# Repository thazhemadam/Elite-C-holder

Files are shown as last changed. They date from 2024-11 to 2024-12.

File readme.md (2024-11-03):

# splinterface

splinterface is an MCU holder, intended for use in both standalone and split builds.

## MCU Support

The following footprints are supported by the holder.

* [Elite-C footprint](https://deskthority.net/wiki/Elite-C)
* [nice!nano footprint](https://nicekeyboards.com/docs/nice-nano/pinout-schematic/#pinout)
* [Supermini nrf52840 footprint](https://github.com/joric/nrfmicro/wiki/Alternatives#supermini-nrf52840)

## Features

* [VIK](https://github.com/sadekbaroudi/vik) compliant
* Support for wireless and wired builds (see an example compatibility matrix [below](#compatibility-matrix-with-bastardkb-boards))
* Full-duplex communications support
* Dedicated pin for handedness (optional)
* Dedicated pin for RGB (optional)
* Criss-crossable pins for serial communication

### Wired Builds

* TRRS jack for split communications
* USBLC6-2P6 for ESD protection

### Wireless Builds

* JST-PH connector for connecting a battery
* EG1271 Slide Switches for power switch

## Compatibility Matrix with BastardKB Boards

| | RGB | Wireless | RGB + Wireless [^1] |
|---|:---:|:---:|:---:|
| Skeletyl | ✅ | ✅ | ✅ |
| Charybdis Nano | ✅ | ✅ | ✅ |
| TBK Mini | ✅ | ✅ [^2] | ✅ [^2][^3] |
| Charybdis Mini | ✅ | ✅ [^2] | ✅ [^2][^3] |
| Scylla | ✅ | ✅ [^3] | ❌ |
| Charybdis | ✅ | ✅ [^3] | ❌ |

* Ribbon cable pinout (for the key matrix) compatible with BastardKB's [Dactyl](https://bastardkb.com/dactyls/) and [Charybdis](https://bastardkb.com/charybdis/) series' PCBs.
* Mounting holes are compatible with BastardKB's [Dactyl](https://bastardkb.com/dactyls/) and [Charybdis](https://bastardkb.com/charybdis/) series' cases.

## VIK Certification Card

| Category | Response |
| --- |:---:|
| FPC connector | ✅ |
| Breakout pins | ❌ |
| Supplies: SPI | ✅ |
| Supplies: I2C | ✅ |
| I2C on main PCB | ❌ |
| I2C pull ups | N/A |
| Supplies: RGB | ✅ |
| Supplies: Extra GPIO 1  | Analog/Digital |
| Supplies: Extra GPIO 2  | Analog/Digital |

## License

This work is licensed under a Creative Commons Attribution-NonCommercial-ShareAlike 4.0 International License.

[^1]: Do you even really want to have RGB with a wireless build? Do you, *really*? For obvious battery-related reasons, this is not a recommended build configuration.
[^2]: Requires the `RGB_OR_WL_COL` jumper to be manually soldered appropriately.
[^3]: Requires the `split_hand_or_row` jumper to be manually soldered appropriately. This will reappropriate the dedicated handedness pin. In this case, the handedness will have to be defined in the firmware.

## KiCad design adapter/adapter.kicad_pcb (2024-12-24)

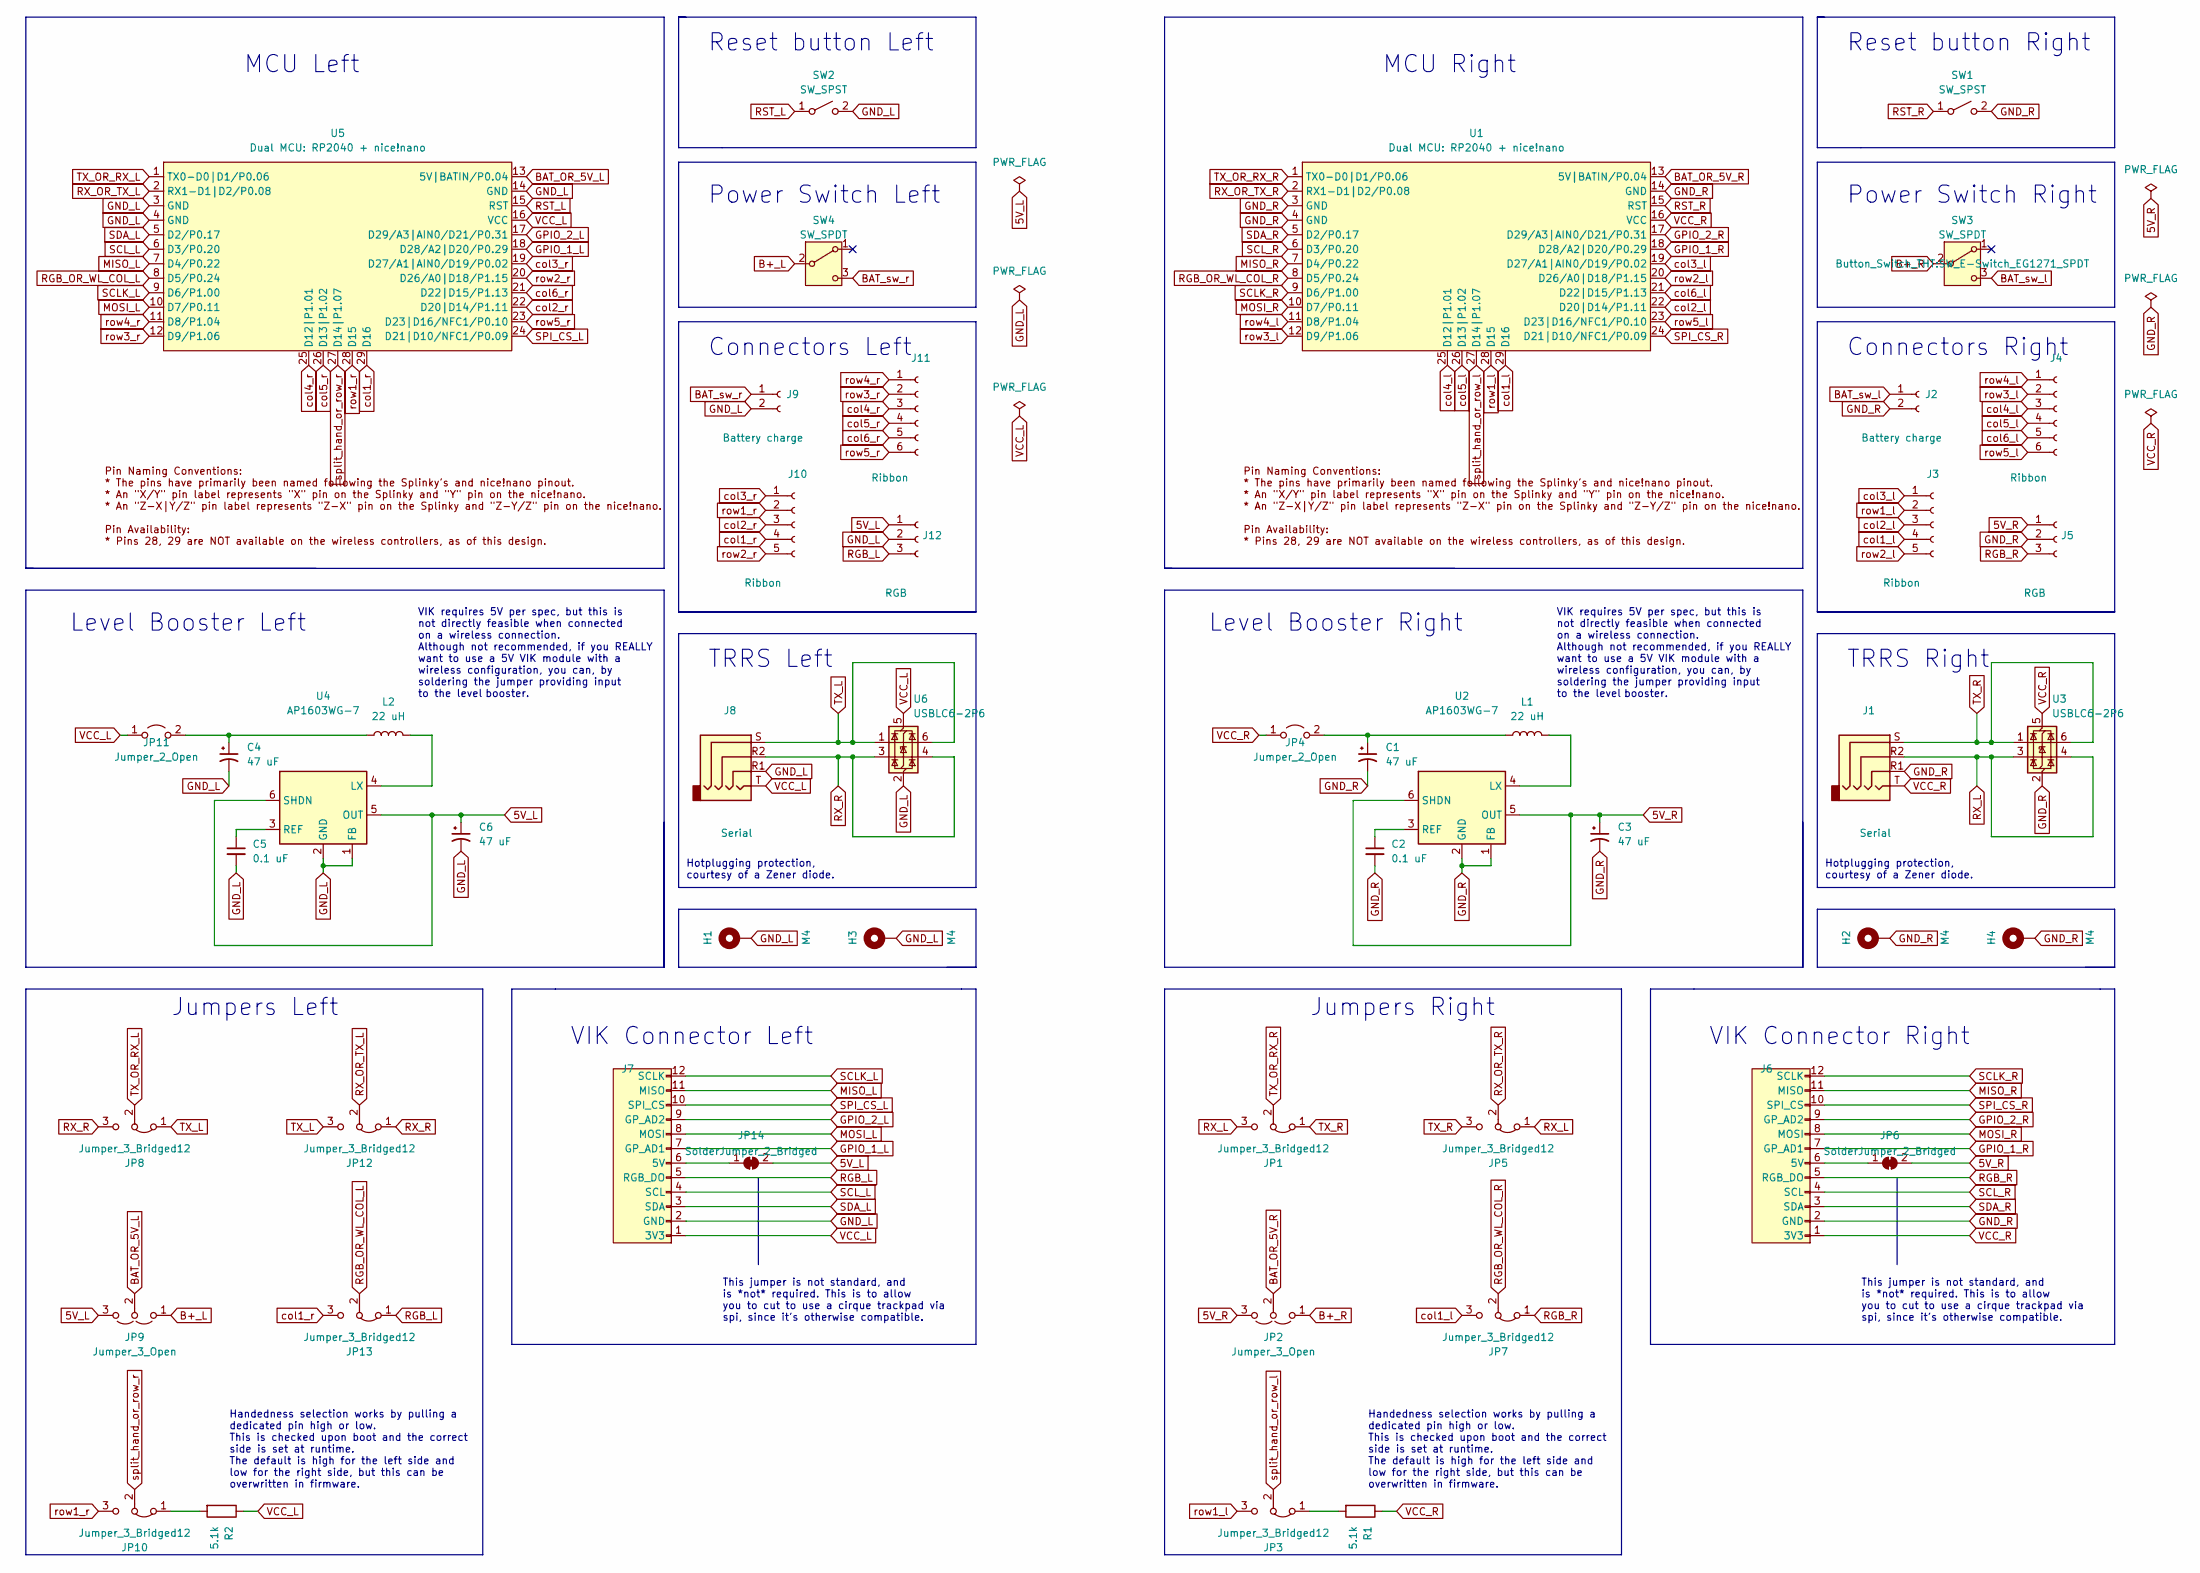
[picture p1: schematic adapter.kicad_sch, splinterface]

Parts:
C1, C3, C4, C6: 47 uF; C_0805_2012Metric; LCSC C140782
C2, C5: 0.1 uF; C_0805_2012Metric; LCSC C1525
H1, H2, H3, H4: M4; MountingHole_4mm_Pad_thin
J1, J8: Serial; CON_MJ-4PP-9
J2, J9: Battery charge; JST_PH_B2B-PH-K_1x02_P2.00mm_Vertical
J3, J10: Ribbon; 5_PinHeader
J4, J11: Ribbon; 6_PinHeader
J5, J12: RGB; header1x03
J6, J7: vik-keyboard-connector-horizontal; LCSC C479750
JP1, JP3, JP5, JP7, JP8, JP10, JP12, JP13: Jumper_3_Bridged12; SolderJumper-3_P1.3mm_Bridged12_RoundedPad1.0x1.5mm
JP2, JP9: Jumper_3_Open; SolderJumper-3_P1.3mm_Open_RoundedPad1.0x1.5mm_NumberLabels
JP4, JP11: Jumper_2_Open; SolderJumper-2_P1.3mm_Open_RoundedPad1.0x1.5mm
JP6, JP14: SolderJumper_2_Bridged; SolderJumper-2_P1.3mm_Bridged_RoundedPad1.0x1.5mm
L1, L2: 22 uH; L_0805_2012Metric; LCSC C361669
R1, R2: 5.1k; R_1206_handsolder; JLCPCB BOM 1
SW1, SW2: SW_SPST; PushSwitch
SW3, SW4: SW_SPDT; SW_E-Switch_EG1271_SPDT
U1, U5: Dual MCU: RP2040 + nice!nano; Dual-MCU-rp2040-nice-nano
U2, U4: AP1603WG-7; SOT-23-6; LCSC C192712
U3, U6: USBLC6-2P6; SOT-23-6

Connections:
5V_L: C6.1, J12.1, JP9.3 (B), JP14.2 (B), U4.5 (OUT), U4.6 (SHDN)
5V_R: C3.1, J5.1, JP2.3 (B), JP6.2 (B), U2.5 (OUT), U2.6 (SHDN)
B+_L: JP9.1 (A), SW4.2 (B)
B+_R: JP2.1 (A), SW3.2 (B)
BAT_OR_5V_L: JP9.2 (C), U5.13 (5V|BATIN/P0.04)
BAT_OR_5V_R: JP2.2 (C), U1.13 (5V|BATIN/P0.04)
BAT_sw_l: J2.1, SW3.3 (C)
BAT_sw_r: J9.1, SW4.3 (C)
GND_L: C4.2, C5.2, C6.2, H1.1, H3.1, J7.2 (GND), J8.R1, J9.2, J12.2, SW2.2 (B), U4.1 (FB), U4.2 (GND), U5.3 (GND), U5.4 (GND), U5.14 (GND), U6.2 (GND)
GND_R: C1.2, C2.2, C3.2, H2.1, H4.1, J1.R1, J2.2, J5.2, J6.2 (GND), SW1.2 (B), U1.3 (GND), U1.4 (GND), U1.14 (GND), U2.1 (FB), U2.2 (GND), U3.2 (GND)
GPIO_1_L: J7.7 (GP_AD1), U5.18 (D28/A2|D20/P0.29)
GPIO_1_R: J6.7 (GP_AD1), U1.18 (D28/A2|D20/P0.29)
GPIO_2_L: J7.9 (GP_AD2), U5.17 (D29/A3|AIN0/D21/P0.31)
GPIO_2_R: J6.9 (GP_AD2), U1.17 (D29/A3|AIN0/D21/P0.31)
MISO_L: J7.11 (MISO), U5.7 (D4/P0.22)
MISO_R: J6.11 (MISO), U1.7 (D4/P0.22)
MOSI_L: J7.8 (MOSI), U5.10 (D7/P0.11)
MOSI_R: J6.8 (MOSI), U1.10 (D7/P0.11)
unnamed: J6.6 (5V), JP6.1 (A)
unnamed: J7.6 (5V), JP14.1 (A)
unnamed: JP3.1 (A), R1.2
unnamed: C1.1, JP4.2 (B), L1.1
unnamed: JP10.1 (A), R2.2
unnamed: C4.1, JP11.2 (B), L2.1
unnamed: L1.2, U2.4 (LX)
unnamed: C2.1, U2.3 (REF)
unnamed: L2.2, U4.4 (LX)
unnamed: C5.1, U4.3 (REF)
RGB_L: J7.5 (RGB_DO), J12.3, JP13.1 (A)
RGB_OR_WL_COL_L: JP13.2 (C), U5.8 (D5/P0.24)
RGB_OR_WL_COL_R: JP7.2 (C), U1.8 (D5/P0.24)
RGB_R: J5.3, J6.5 (RGB_DO), JP7.1 (A)
RST_L: SW2.1 (A), U5.15 (RST)
RST_R: SW1.1 (A), U1.15 (RST)
RX_L: J1.R2, JP1.3 (B), JP5.1 (A), U3.3 (I/O2), U3.4 (I/O2)
RX_OR_TX_L: JP12.2 (C), U5.2 (RX1-D1|D2/P0.08)
RX_OR_TX_R: JP5.2 (C), U1.2 (RX1-D1|D2/P0.08)
RX_R: J8.R2, JP8.3 (B), JP12.1 (A), U6.3 (I/O2), U6.4 (I/O2)
SCLK_L: J7.12 (SCLK), U5.9 (D6/P1.00)
SCLK_R: J6.12 (SCLK), U1.9 (D6/P1.00)
SCL_L: J7.4 (SCL), U5.6 (D3/P0.20)
SCL_R: J6.4 (SCL), U1.6 (D3/P0.20)
SDA_L: J7.3 (SDA), U5.5 (D2/P0.17)
SDA_R: J6.3 (SDA), U1.5 (D2/P0.17)
SPI_CS_L: J7.10 (SPI_CS), U5.24 (D21|D10/NFC1/P0.09)
SPI_CS_R: J6.10 (SPI_CS), U1.24 (D21|D10/NFC1/P0.09)
TX_L: J8.S, JP8.1 (A), JP12.3 (B), U6.1 (I/O1), U6.6 (I/O1)
TX_OR_RX_L: JP8.2 (C), U5.1 (TX0-D0|D1/P0.06)
TX_OR_RX_R: JP1.2 (C), U1.1 (TX0-D0|D1/P0.06)
TX_R: J1.S, JP1.1 (A), JP5.3 (B), U3.1 (I/O1), U3.6 (I/O1)
VCC_L: J7.1 (3V3), J8.T, JP11.1 (A), R2.1, U5.16 (VCC), U6.5 (VBUS)
VCC_R: J1.T, J6.1 (3V3), JP4.1 (A), R1.1, U1.16 (VCC), U3.5 (VBUS)
col1_l: J3.4, JP7.3 (B), U1.29 (D16)
col1_r: J10.4, JP13.3 (B), U5.29 (D16)
col2_l: J3.3, U1.22 (D20|D14/P1.11)
col2_r: J10.3, U5.22 (D20|D14/P1.11)
col3_l: J3.1, U1.19 (D27/A1|AIN0/D19/P0.02)
col3_r: J10.1, U5.19 (D27/A1|AIN0/D19/P0.02)
col4_l: J4.3, U1.25 (D12|P1.01)
col4_r: J11.3, U5.25 (D12|P1.01)
col5_l: J4.4, U1.26 (D13|P1.02)
col5_r: J11.4, U5.26 (D13|P1.02)
col6_l: J4.5, U1.21 (D22|D15/P1.13)
col6_r: J11.5, U5.21 (D22|D15/P1.13)
row1_l: J3.2, JP3.3 (B), U1.28 (D15)
row1_r: J10.2, JP10.3 (B), U5.28 (D15)
row2_l: J3.5, U1.20 (D26/A0|D18/P1.15)
row2_r: J10.5, U5.20 (D26/A0|D18/P1.15)
row3_l: J4.2, U1.12 (D9/P1.06)
row3_r: J11.2, U5.12 (D9/P1.06)
row4_l: J4.1, U1.11 (D8/P1.04)
row4_r: J11.1, U5.11 (D8/P1.04)
row5_l: J4.6, U1.23 (D23|D16/NFC1/P0.10)
row5_r: J11.6, U5.23 (D23|D16/NFC1/P0.10)
split_hand_or_row_l: JP3.2 (C), U1.27 (D14|P1.07)
split_hand_or_row_r: JP10.2 (C), U5.27 (D14|P1.07)

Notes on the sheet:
Handedness selection works by pulling a dedicated pin high or low. This is checked upon boot and the correct side is set at runtime. The default is high for the left side and low for the right side, but this can be overwritten in firmware.
Reset button Right
VIK requires 5V per spec, but this is not directly feasible when connected on a wireless connection. Although not recommended, if you REALLY want to use a 5V VIK module with a wireless configuration, you can, by soldering the jumper providing input to the level booster.
TRRS Right
Jumpers Right
Jumpers Left
Connectors Left
Reset button Left
Power Switch Right
Level Booster Left
This jumper is not standard, and is *not* required. This is to allow you to cut to use a cirque trackpad via spi, since it's otherwise compatible.
Power Switch Left
MCU Right
Hotplugging protection, courtesy of a Zener diode.
VIK Connector Left
Connectors Right
VIK Connector Right
MCU Left
Level Booster Right
TRRS Left

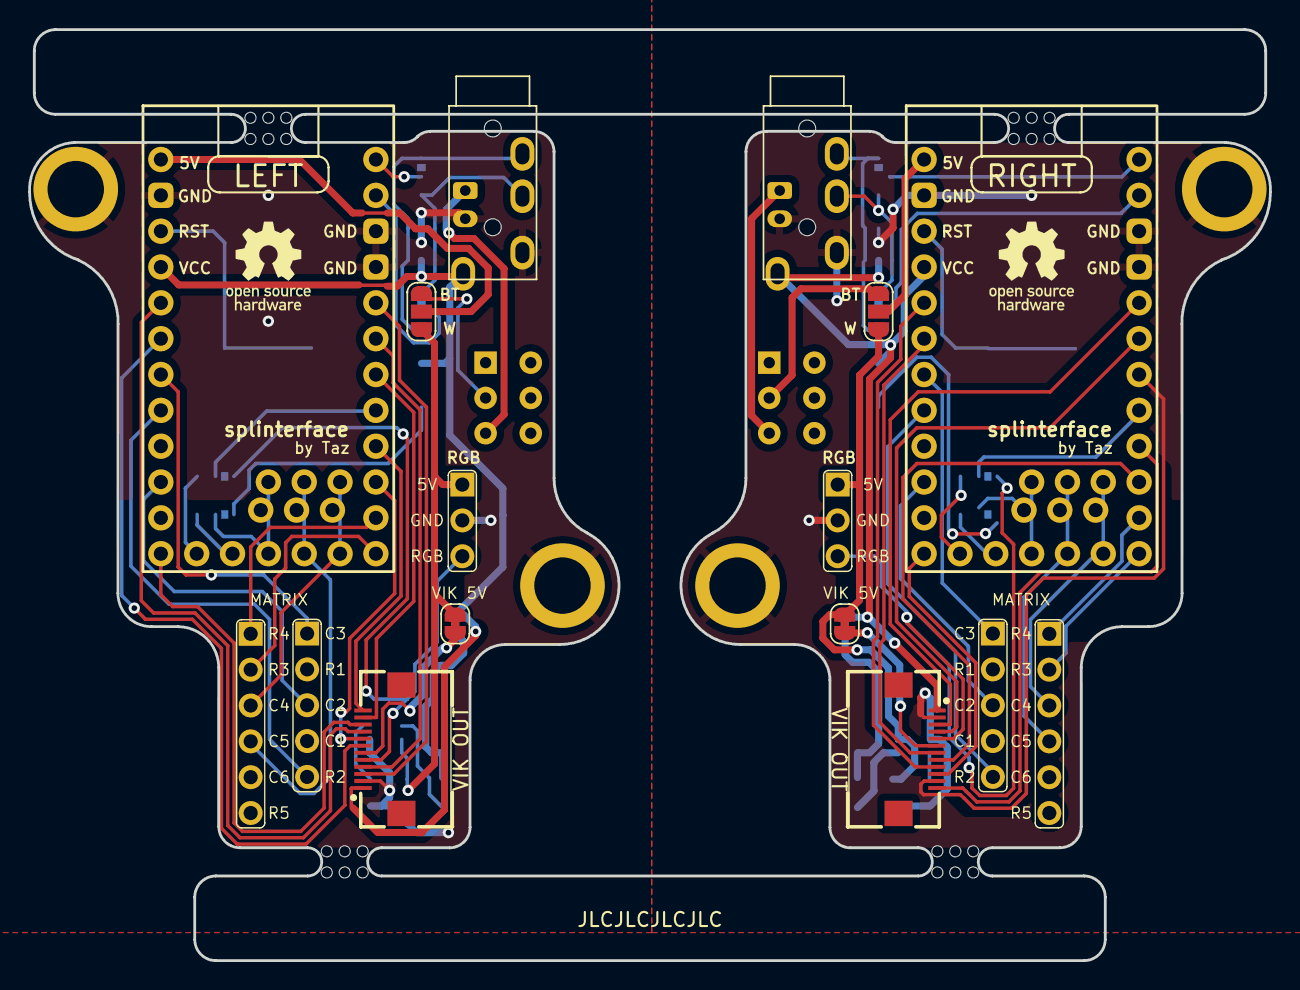
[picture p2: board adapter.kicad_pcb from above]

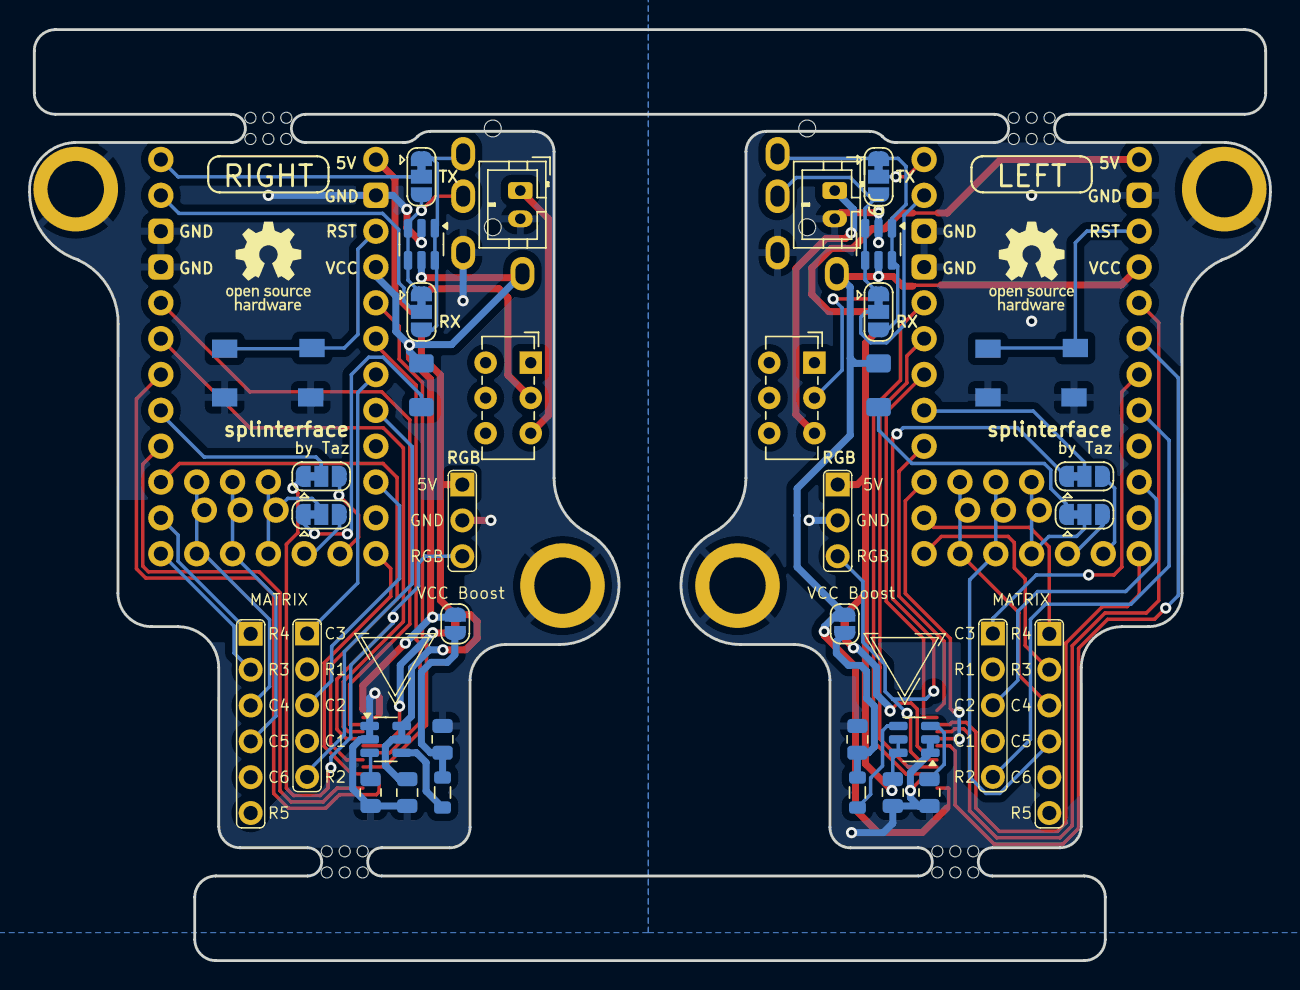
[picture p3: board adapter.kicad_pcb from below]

Board: 2 copper layers, 87.9 x 66.0 mm, 54 parts (33 on the bottom side), 76 nets.

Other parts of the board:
H5, H7: Mousebite-Top; mousebites
H6, H8: Mousebite-Bottom; mousebites

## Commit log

2024-05-06 update to kicad v8
    [adapter.kicad_pcb, adapter.kicad_sch]
2024-05-06 pcb: remove extraneous drawings
    [adapter.kicad_pcb]
2024-05-06 remove silk screen for trackball breakout
    [adapter.kicad_pcb]
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2024-05-06 sch: align items to grid
    [adapter.kicad_sch]
2024-05-06 sch: update footprints from library
    [adapter.kicad_sch]
2024-05-06 sch: update footprints to newer versions
    [adapter.kicad_sch]
2024-05-06 sch: fix more erc errors
    [adapter.kicad_sch]
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2024-05-06 sch: use original `Library` elite-c footprint
    [adapter.kicad_sch]
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2024-05-07 pcb: remove all traces
    [adapter.kicad_pcb]
2024-05-08 sch: replace elite-c symbol with dual-rp2040-nicenano symbol
    [adapter.kicad_sch]
2024-05-08 pcb: remove no longer relevant silkscreen text
    [adapter.kicad_pcb]
2024-05-08 pcb: update the all the footprints to use `library`
    [adapter.kicad_pcb, adapter.kicad_sch]
2024-05-08 pcb: update footprints from library
    [adapter.kicad_pcb]
2024-05-08 pcb: update some silkscreen
    [adapter.kicad_pcb]
2024-05-08 sch: remove I2C breakouts
    [adapter.kicad_sch]
2024-05-08 pcb: remove I2C breakouts
    [adapter.kicad_pcb]
2024-05-08 sch: update symbols from library
    [adapter.kicad_sch]
2024-05-21 pcb(edge-cuts): remove right hand side edge cuts
    [adapter.kicad_pcb]
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2024-05-21 pcb(edge-cuts): true symmetry! add rhs too
    [adapter.kicad_pcb]
2024-05-21 pcb: remove all footprints for rhs
    [adapter.kicad_pcb]
2024-05-21 pcb: fix outline drc errors
    [adapter.kicad_pcb]
2024-05-21 pcb: remove middle breakoff partition
    [adapter.kicad_pcb]
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2024-05-21 wip: sch: update MCU pins per VIK requirements slightly
    [adapter.kicad_sch]
2024-05-22 sch: update schematic from library
    [adapter.kicad_sch]
2024-05-22 sch: remove I2C pullups from the adapter board
    Remove I2C pullups from the adapter board since it's the responsibility
    of the respective VIK modules (e.g., the VIK trackball sensor PCB) to
    provide I2C pullups.[^1]
    [^1]: https://github.com/sadekbaroudi/vik/blob/96d1c2e098b2f305df47dd9c50749a866b508be5/README.md#module-pcb
    [adapter.kicad_sch]
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2024-06-07 pcb: update mcu footprint and adjust edge cuts
    [adapter.kicad_pcb]
2024-06-08 pcb: add VIK FFC connector footprint
    [adapter.kicad_pcb, adapter.kicad_sch]
2024-08-17 sch: properly assign spi pins
    [adapter.kicad_sch]
2024-08-17 sch: add vik connector with jumper to cut for cirque
    [adapter.kicad_sch]
2024-08-17 sch: add jumpers for handling 5v
    [adapter.kicad_sch]
2024-08-17 sch: add voltage boost circuit
    [adapter.kicad_sch]
2024-08-17 sch: fix up erc violations and issues
    [adapter.kicad_sch]
2024-08-19 always have voltage convertor on
    [adapter.kicad_sch]
2024-08-19 pcb: add 3d model for trrs jack
    [adapter.kicad_pcb]
2024-08-19 pcb: remove random silkscreen
    [adapter.kicad_pcb]
2024-08-19 pcb: position trrs jack perfectly
    [adapter.kicad_pcb]
2024-08-19 pcb: use 3d model of splinky for mcu
    [adapter.kicad_pcb]
2024-08-19 pcb: update from schematic
    [adapter.kicad_pcb]
2024-08-19 sch: organize different things
    [adapter.kicad_pcb, adapter.kicad_sch]
2024-08-29 sch: remove booster circuit
    [adapter.kicad_sch]
2024-08-29 sch: add jumpers for supporting row 5 and col 6
    [adapter.kicad_sch]
2024-08-29 sch: add footprints for jumpers
    [adapter.kicad_pcb, adapter.kicad_sch]
2024-08-29 fix up jumpers
    [adapter.kicad_sch]
2024-08-29 sch: use zener diode protection circuit with 2.2k resistor
    [adapter.kicad_sch]
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2024-08-29 sch: add booster circuit
    [adapter.kicad_sch]
2024-08-29 sch: add jumpers for swapping rx and tx
    [adapter.kicad_sch]
2024-09-15 sch: fix up level booster circuit
    [adapter.kicad_sch]
2024-09-15 sch: move (potential) RGB pin to a high freq pin & CS to a low freq pin
    [adapter.kicad_pcb, adapter.kicad_sch]
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2024-09-15 pcb: position tx and rx jumpers
    [adapter.kicad_pcb]
2024-09-15 pcb: wire up col and row pins
    [adapter.kicad_pcb, adapter.kicad_sch]
2024-09-15 sch: pull up left-handedness with 3.3v
    [adapter.kicad_sch]
2024-09-15 pcb: update pcb from schematic
    [adapter.kicad_pcb]
2024-09-15 pcb: wire up spi and i2c
    [adapter.kicad_pcb]
2024-09-15 pcb: remove switch. find nicer place for it
    [adapter.kicad_pcb]
2024-09-15 pcb: define thicc netclass group for pwr traces
    [adapter.kicad_pcb]
2024-09-15 pcb: fix up drc
    [adapter.kicad_pcb]
2024-09-15 pcb: route vik gpios
    [adapter.kicad_pcb, adapter.kicad_sch]
2024-09-15 pcb: wire up 3v3 rgb and 5v
    [adapter.kicad_pcb]
2024-09-15 pcb: 3d models for headers
    [adapter.kicad_pcb]
2024-09-15 pcb: 3d model for tactile reset switch
    [adapter.kicad_pcb, adapter.kicad_sch]
2024-09-15 pcb: fix jst-ph orientation
    [adapter.kicad_pcb]
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2024-09-15 pcb: add handedness pin
    [adapter.kicad_pcb]
2024-09-15 libs(adapter): have solder mask only on one side for MCU
    [adapter.kicad_pcb]
2024-09-15 pcb: update footprint from library
    [adapter.kicad_pcb]
2024-09-15 pcb: make level booster circuit components all 0805 size
    [adapter.kicad_pcb, adapter.kicad_sch]
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2024-09-15 pcb: fix drc
    [adapter.kicad_pcb]
2024-09-16 sch: replace zener diode + resistor with TVS
    [adapter.kicad_sch]
2024-09-16 sch: use level booster symbol from symbol library
    [adapter.kicad_sch]
2024-09-16 pcb: use TVS and update pcb from schematic
    [adapter.kicad_pcb]
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2024-09-16 sch: update types of jumpers
    [adapter.kicad_sch]
2024-09-16 pcb: update types of jumpers
    [adapter.kicad_pcb]
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2024-09-17 pcb: centre vias and switch between the MCU
    [adapter.kicad_pcb]
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2024-09-17 sch: add different pwr flags for lhs and rhs
    [adapter.kicad_sch]
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2024-09-17 pcb: update VIK footprint to move silk screen around
    [adapter.kicad_pcb]
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2024-09-27 WIP - RECORD POSITIONS AND REVERT
    [adapter.kicad_pcb]
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2024-09-28 sch: replace rows and cols for convenient routing
    [adapter.kicad_sch]
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2024-09-29 libs(adapter): silkscreen fixup
    [adapter.kicad_pcb]
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2024-09-29 pcb: position booster circuit correctly
    [adapter.kicad_pcb]
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2024-09-29 pcb: flip lhs
    [adapter.kicad_pcb]
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2024-09-29 pcb: fix up ground zone for lhs
    [adapter.kicad_pcb]
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2024-09-29 pcb: place components for lhs correctly
    [adapter.kicad_pcb]
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2024-10-26 pcb: flip silkscreens correctly
    [adapter.kicad_pcb]
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2024-10-26 pcb: swap lhs and rhs sides
    [adapter.kicad_pcb]
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2024-10-26 pcb: fix rx tx silks
    [adapter.kicad_pcb]
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2024-10-26 sch: fix names of boxes
    [adapter.kicad_pcb, adapter.kicad_sch]
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2024-11-03 pcb: correctly swap L and R labels in schematic
    [adapter.kicad_pcb, adapter.kicad_sch]
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2024-11-26 libs(adapter): fix GPIO number on footprint, add GPIO number for ADC
    [adapter.kicad_sch]
2024-11-26 fix: swap col6 and col1
    [adapter.kicad_sch]
2024-11-26 fix: swap row5 and row1
    [adapter.kicad_sch]
2024-12-24 fix: swap miso and mosi
    [adapter.kicad_pcb, adapter.kicad_sch]
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2024-12-24 fix: swap row1 and col1 for easier routing
    [adapter.kicad_sch]
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

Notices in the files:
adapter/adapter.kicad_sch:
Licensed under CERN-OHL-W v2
